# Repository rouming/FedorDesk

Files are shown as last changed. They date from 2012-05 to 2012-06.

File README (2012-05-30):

NAME
    FedorDesk -- firmware for toy with 3 buttons, 12 leds and 1 mario-theme
    sound.

AUTHOR
    Roman Pen

USERS
    son Fedor

ACKNOWLEDGEMENTS
COPYRIGHT & LICENSE
    Copyright 2012 Roman Pen

    This program is free software; you can redistribute it and/or modify it
    under the terms of either: the GNU General Public License as published
    by the Free Software Foundation

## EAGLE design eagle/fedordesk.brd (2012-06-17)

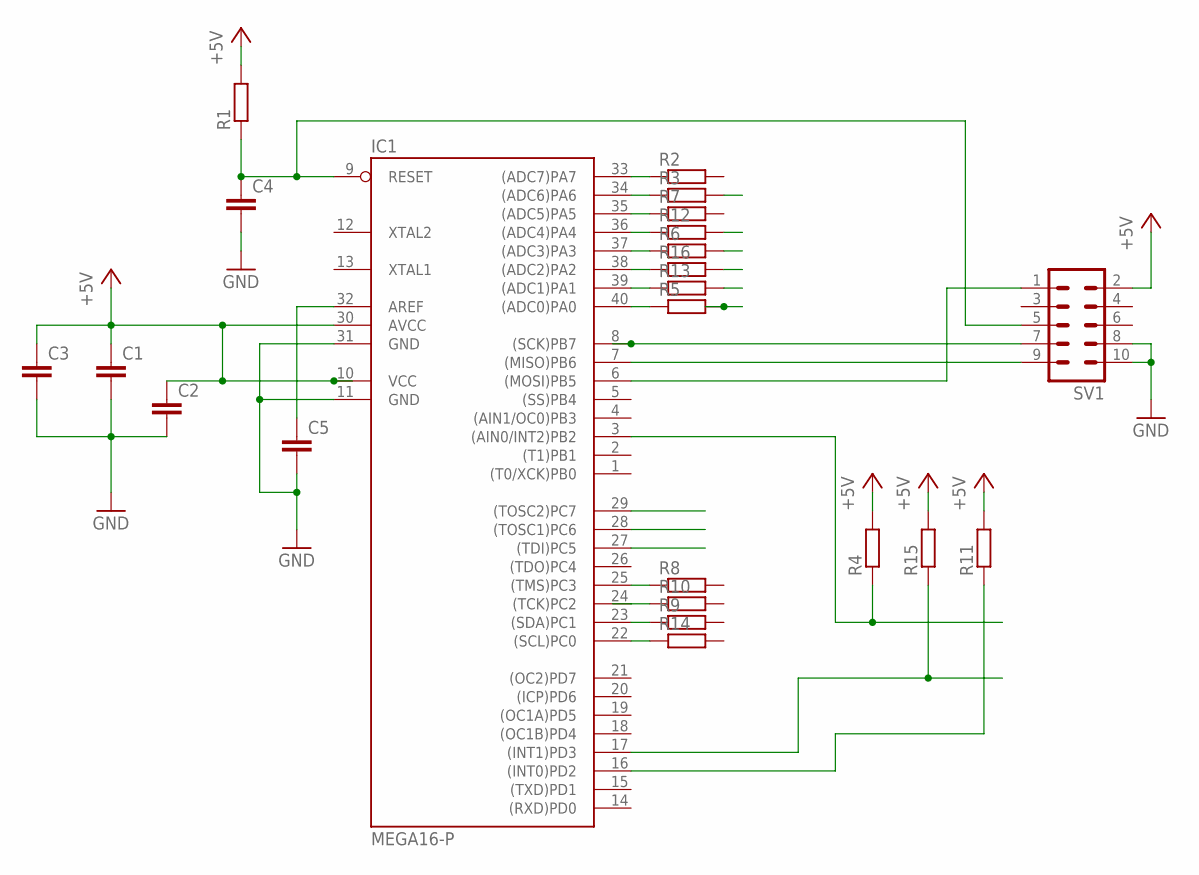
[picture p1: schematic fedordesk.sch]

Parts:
C1, C2, C3, C4, C5: C-EU050-024X044; C050-024X044
IC1: MEGA16-P; DIL40
R1, R2, R3, R4, R5, R6, R7, R8, R9, R10, R11, R12, R13, R14, R15, R16: R-EU_0207/10; 0207/10
SV1: ML10L

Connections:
+5V: C1.1, C2.1, C3.1, IC1.10 (VCC), IC1.30 (AVCC), R1.2, R4.2, R11.2, R15.2, SV1.2
GND: C1.2, C2.2, C3.2, C4.2, C5.2, IC1.11 (GND), IC1.31 (GND), SV1.8, SV1.10
unnamed: IC1.3 ((AIN0/INT2)PB2), R4.1
unnamed: C5.1, IC1.32 (AREF)
unnamed: IC1.17 ((INT1)PD3), R15.1
unnamed: IC1.16 ((INT0)PD2), R11.1
unnamed: IC1.6 ((MOSI)PB5), SV1.1
unnamed: C4.1, IC1.9 (RESET), R1.1, SV1.5
unnamed: IC1.8 ((SCK)PB7), SV1.7
unnamed: IC1.7 ((MISO)PB6), SV1.9
unnamed: IC1.33 ((ADC7)PA7), R2.1
unnamed: IC1.34 ((ADC6)PA6), R3.1
unnamed: IC1.35 ((ADC5)PA5), R7.1
unnamed: IC1.36 ((ADC4)PA4), R12.1
unnamed: IC1.37 ((ADC3)PA3), R6.1
unnamed: IC1.38 ((ADC2)PA2), R16.1
unnamed: IC1.39 ((ADC1)PA1), R13.1
unnamed: IC1.40 ((ADC0)PA0), R5.1
unnamed: IC1.25 ((TMS)PC3), R8.1
unnamed: IC1.23 ((SDA)PC1), R9.1
unnamed: IC1.22 ((SCL)PC0), R14.1
unnamed: IC1.24 ((TCK)PC2), R10.1

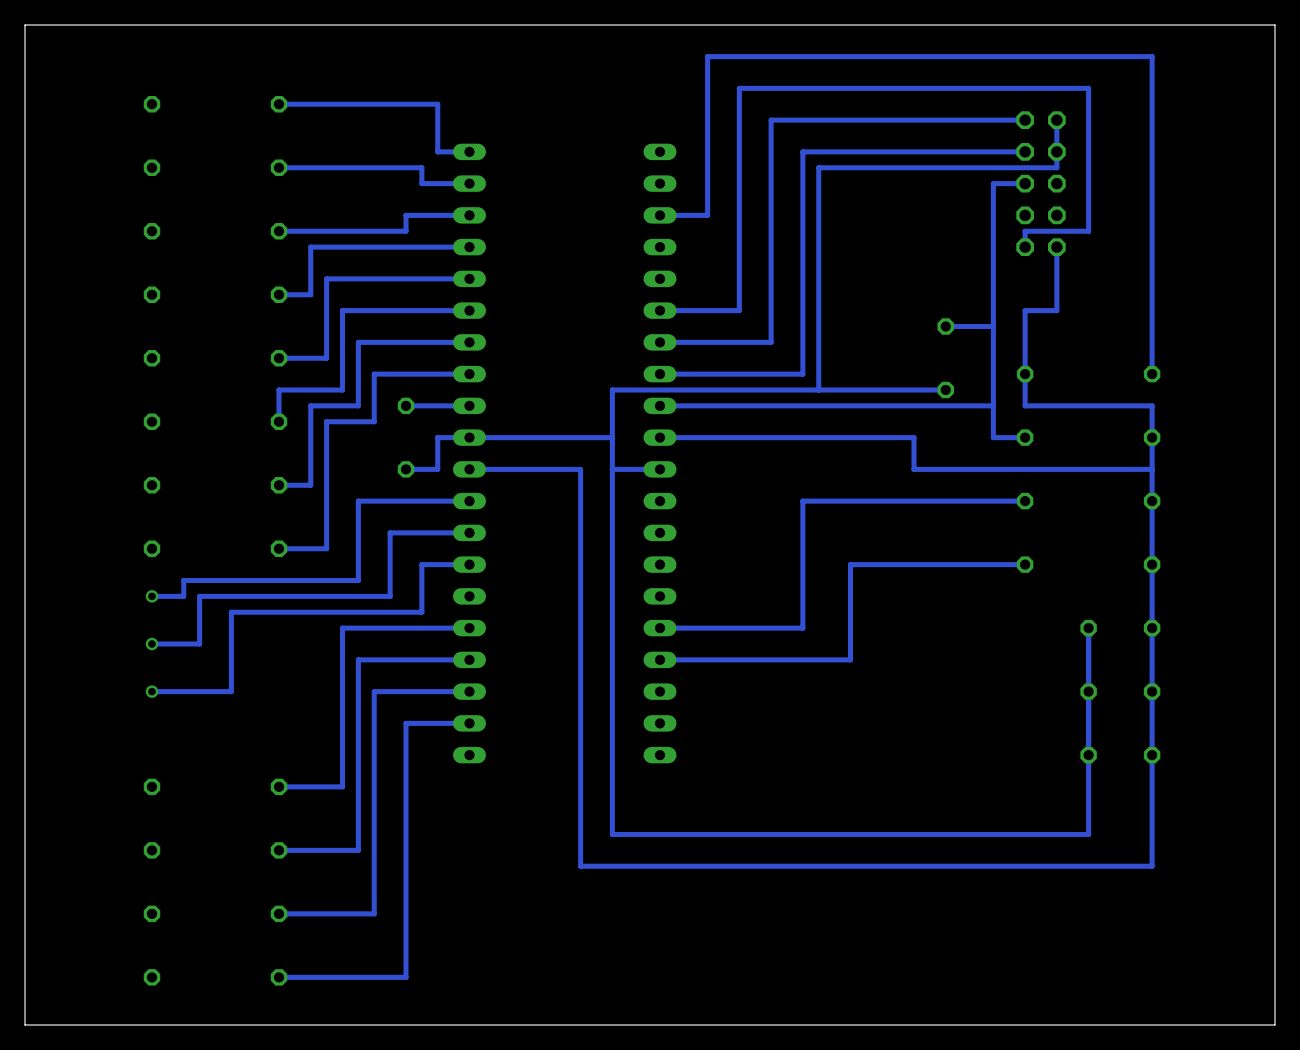
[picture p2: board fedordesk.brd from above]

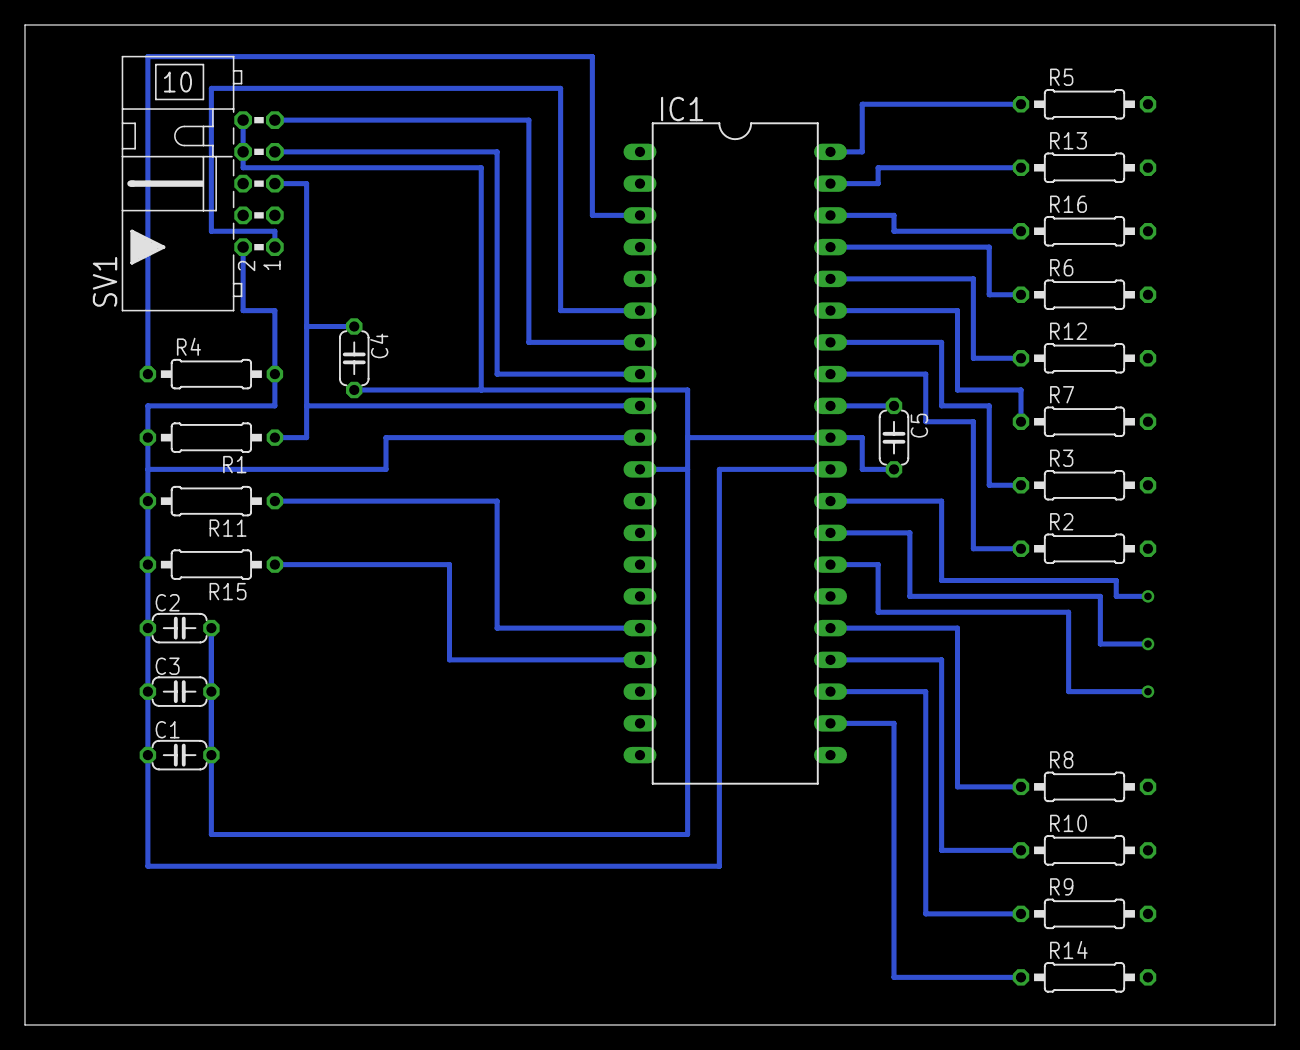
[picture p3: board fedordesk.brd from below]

Board: 2 copper layers, 100.0 x 80.0 mm, 23 parts (23 on the bottom side), 22 nets.

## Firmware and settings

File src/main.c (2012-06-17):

#include <avr/io.h>
#include <avr/interrupt.h>
#include <avr/pgmspace.h>
#include <avr/fuse.h>

#include "sounddata.h"
#include "fedordesk.h"

/*
 * ATMega16
 * TIMER1
 *   We use 16-bit TIMER1 in CTC mode, i.e. interrupt fires
 *   when TCNT1 becomes equal to OCR1A
 *   Every N interrupt we will have 10Hz, i.e. 100ms
 *
 * Timers:
 *     http://easyelectronics.ru/avr-uchebnyj-kurs-tajmery.html
 *
 *     http://maxembedded.wordpress.com/2011/06/24/avr-timers-timer0-2
 *     http://maxembedded.wordpress.com/2011/06/28/avr-timers-timer1
 *     http://maxembedded.wordpress.com/2011/06/28/avr-timers-timer2
 *
 * Audio:
 *     http://avrpcm.blogspot.com/2010/11/playing-8-bit-pcm-using-any-avr.html
 *     http://www.arduino.cc/playground/Code/PCMAudio
 *
 * BUTTON[0..2] -> PD2, PD3, PB2
 * LED[0..11]   -> PA[0..7], PC[0..3]
 * GR[0..2]     -> PC[4..6]
 * PD7          -> out speaker PWM
 *
 */

/**
FUSES =
{
	// LOW FUSE, default - 0b11100001 (0xE1)
	//   - 8MHz internal oscillator - 0b11100100 (0xE4)
	.low  = (LFUSE_DEFAULT & FUSE_CKSEL0 & FUSE_CKSEL1 &
			 FUSE_CKSEL2 & FUSE_CKSEL3) | ~FUSE_CKSEL2,

	// HIGH FUSE, default - 0b10011001 (0x99)
	//   - disabled JTAG - 0b11011001 (0xD9)
	.high = HFUSE_DEFAULT | ~FUSE_JTAGEN
};
**/

#define SAMPLE_RATE 8000 // playback rate, hz
#define CB_RATE     10   // callback rate, hz

// leds state
static uint8_t s_leds_layer;
static uint16_t	s_leds_state;
static uint16_t s_leds_mask;
static uint8_t s_playback;

// sampler and leds 16-bit timer
static void timer1_init()
{
	// Set CTC mode (Clear Timer on Compare Match) (p.109)
	// Have to set OCR1A *after*, otherwise it gets reset to 0!
	TCCR1B |= (1 << WGM12);

	// No prescaler (p.113)
	TCCR1B |= (1 << CS10);

	// Set the compare register (OCR1A) (p.98-99).
	// Do not forget about -1, because we count from 0
	OCR1A = F_CPU / SAMPLE_RATE - 1;

	// Enable Output Compare Match Interrupt when TCNT1 == OCR1A (p.112)
	TIMSK |= (1 << OCIE1A);
}

// set up Timer 2 to do pulse width modulation on the speaker pin
static void timer2_init()
{
	// Set fast PWM mode  (p.128)
	TCCR2 |= (1 << WGM21) | (1 << WGM20);

	// Do non-inverting PWM on pin OC2 (p.129)
	TCCR2 |= (1 << COM21);

	// No prescaler (p.130)
	TCCR2 |= (1 << CS20);

	// Set initial pulse width to the first sample.
	OCR2 = 0;
}

// deinit PWM timer2
static void timer2_deinit()
{
	// disable PWM timer
	TCCR2 &= ~(1 << CS20);

	// PWM pin to low
	PORTD &= ~(1 << DDD7);
}

static void start_playback()
{
	if (s_playback)
		return;
	s_playback = 1;
	timer2_init();
}

static void stop_playback()
{
	if (!s_playback)
		return;
	s_playback = 0;
	timer2_deinit();
}

static void external_int_init()
{
	// enable falling edge on INT0, INT1
	MCUCR |= (1<<ISC01) | (1<<ISC11);
	// enable falling edge on INT2
	MCUCSR &= ~(1<<ISC2);

	// enable INT0, INT1, INT2
	GICR |= (1<<INT0) | (1<<INT1) | (1<<INT2);
}

static void init_io_ports()
{
	/*
	 * LED[0..11]   -> PA[0..7], PC[0..3]
	 * GR[0..2]     -> PC[4..6]
	 * PD7 -> out speaker PWM
	 */

	// 0..7 A pins as output
	DDRA |= 0b11111111;
	// 0..3 C pins as output
	DDRC |= 0b00001111;
	// 4..6 C pins as output
	DDRC |= 0b01110000;
	// PWM speaker pin as out
	DDRD = (1 << DDD7);

	// 0..7 A pins to low
	PORTA &= ~0b11111111;
	// 0..3 C pins to low
	PORTC &= ~0b00001111;
	// 4..6 C pins to low
	PORTC &= ~0b01110000;
}

static void hw_fire_leds(const uint16_t* leds, uint8_t y)
{
	// save leds state
	s_leds_layer = y;
	s_leds_state = *leds;
	// 6 max fired leds at a time
	// 20mA * 6 = 120mA max
	s_leds_mask = 0b111111;
}

static void fire_leds()
{
	// firstly turn off leds

	// 0..7 A pins to low
	PORTA &= ~0b11111111;
	// 0..3 C pins to low
	PORTC &= ~0b00001111;
	// 4..6 C pins to low
	PORTC &= ~0b01110000;

	// nothing to do
	if (!s_leds_state)
		return;

	// toggle mask
	s_leds_mask ^= 0b111111111111;

	// current fired leds
	uint16_t leds = s_leds_state & s_leds_mask;

	// turn on led
	PORTA |= (leds & 0xff);
	PORTC |= ((leds >> 8) & 0b1111);

	// turn on ground
	PORTC |= (1 << ((s_leds_layer % LAYERS_NUM) + 4));
}

static void load_audio_sample()
{
	static uint16_t s_sample = 0;

	// read audio sample byte to PWM compare register
	OCR2 = pgm_read_byte(&s_samples[s_sample++ % sizeof(s_samples)]);

	// avoid overflow
	s_sample = s_sample % sizeof(s_samples);
}

// TIMER1 Output Compare Match Interrupt service routine
// works on SAMPLE_RATE
ISR(TIMER1_COMPA_vect)
{
	// global variable to count the number of overflows
	static uint16_t s_overflow = 0;

	// play audio
	load_audio_sample();

	// fire leds on every interrupt for power savings
	// i.e. do persistence of vision (pov) with frequent flicking
	fire_leds();

	// call desk callback
	if (++s_overflow == SAMPLE_RATE / CB_RATE) {
		desk_timer_100ms_callback();

		// reset overflow counter
		s_overflow = 0;
	}
}

ISR(INT0_vect)
{
	if (button_unknown == desk_button_pressed(button0))
		stop_playback();
	else
		start_playback();
}

ISR(INT1_vect)
{
	if (button_unknown == desk_button_pressed(button1))
		stop_playback();
	else
		start_playback();
}

ISR(INT2_vect)
{
	if (button_unknown == desk_button_pressed(button2))
		stop_playback();
	else
		start_playback();
}

int main()
{
	// init io ports
	init_io_ports();

	// init sampler and leds timer
	timer1_init();

	// init external interrupts
	external_int_init();

	// init leds
	desk_init_leds(&hw_fire_leds);

	// enable global interrupts
	sei();

	// loop forever
	while(1)
		;

	return 0;
}

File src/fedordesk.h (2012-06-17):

#ifndef FEDORDESK_H
#define FEDORDESK_H

#include <avr/io.h>

typedef enum led_speed {
	led_speed0 = 0,
	led_speed1 = 1,
	led_speed2 = 2
} led_speed_t;

typedef enum button {
	button_unknown = 0,
	button0 = 1,
	button1 = 2,
	button2 = 3
} button_t;

typedef void (*hw_fire_leds_t)(const uint16_t* leds, uint8_t y);

typedef struct led_state {
	led_speed_t    speed;
	button_t       last_pressed_b;
	uint32_t       last_pressed_ms;
	uint16_t       leds_matrix[3];
	uint32_t       timer_counter;
	hw_fire_leds_t hw_fire_leds;
} led_state_t;

#define LEDS_NUM    12
#define LAYERS_NUM  3
#define BUTTONS_NUM 3

void desk_init_leds(hw_fire_leds_t cb);
button_t desk_button_pressed(button_t b);
void desk_timer_100ms_callback();

#endif //FEDORDESK_H

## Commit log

2012-04-03 finish with leds
2012-04-03 fix lost bit for last led
    [main.c]
2012-04-05 fix timer#0 enabling, fix prescaler according to 1MHz
    [fedor_desk.DSN]
2012-04-05 drop ground at any call hw_fire_leds
2012-04-05 fire leds fixes
    [fedor_desk.DSN]
2012-04-16 save power with persistence of vision
    i.e. never fire on all leds, but try to do frequent flickering.
    every time we have only one led on (current ~20mA)
2012-04-16 fix timer interrupts when prescaler is off
    [main.c]
2012-04-22 update proteus scheme and sources, change ground wires
    [fedor_desk.DSN]
2012-05-10 Now ground is turned by H not by L
2012-05-11 count 100ms in timer more accurate
2012-05-16 increase default leds speed
2012-05-18 Generating hex just on flash rule, also read fuses cmd
2012-05-19 remove big delay of while in timer interrupt
2012-05-19 timer0 in CTC mode, i.e. it fires not by 8-bit overflow (256) but when TCNT0 == OCR0
2012-05-20 audio playing implementation on PWM using timer2
2012-05-21 update isis scheme
    [fedor_desk.DSN]
2012-05-21 for firing leds and sound sampling use 16-bit timer1 instead of 8-bit timer0
2012-05-21 minor sample rate correction (forgotten -1)
    [main.c]
2012-05-21 fix prescaler for timer1
    [main.c]
2012-05-22 implement deinition procedure for PWM timer2
2012-05-22 some fuses tweaks in makefile and in sources
2012-06-17 toggle start/stop playback on button press
2012-06-17 add eagle scheme and board projects
    [fedordesk.brd, fedordesk.sch]
2012-06-18 rename fedor_desk.DSN -> proteus/fedordesk.dsn
    [fedordesk.dsn]
